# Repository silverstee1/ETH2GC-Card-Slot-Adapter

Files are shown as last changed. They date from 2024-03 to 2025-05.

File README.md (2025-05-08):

# ETH2GC-Card-Slot-Adapter
ETH2GC Card Slot PCB, Case Files

Card Slot Adapter on the front of the Gamecube for the ETH2GC BBA Emulation Project made by Extrems & WebHDX collab using the ENC28J60 Module.

https://github.com/Extrems

https://github.com/webhdx

~~BBA Emulation is not currently supported on the front slots but other network features such as FSP and Disc/IPL Dumping and more are accessible see swiss-gc github for more details.~~

As of swiss_1644 artifact build and Swiss Release Swiss v0.6r1664, BBA emulation has been added to Swiss Hypervisor and works on the front slots. See swiss build commit for more details.

Disc iso streaming is not supported on the ENC28J60

https://github.com/emukidid/swiss-gc

# Check out the newer, smaller, and more powerful card slot version based on the W5500 module below

https://github.com/silverstee1/WizNet-Card-Slot-Adapter - W5500 Version

# PCB Fab:
When ordering for example from JLCPCB, Select 1.6mm PCB thickness with ENIG surface finish for long life wear and tear, I choose HASL for cheap 1 off tests.

On the bottom of the PCB is 2x5 female 2.54mm pin connector soldered to the PCB to mate with the ENC28J60 Module once assembled.

**3D Printing:** I printed in PLA+ with the model standing up, the Ethernet Jack facing down on the build plate with Tree supports set to auto on my FDM Bambu X1C printer.
for the cover I had it facing flat side down on the build plate.

Case modified from WebHDX's Thingiverse gecko case https://www.thingiverse.com/thing:4866325

**Fastening:** I used M2x4 pan head self tapping phillips screws from a generic amazon kit for the 4 screw posts but a better alternative is M2x5 countersunk self tapping screws for a flat smooth finish.

1-min
2-min
3-min
4-min
5-min
6-min
7-min
8-min

**SLIM VERSION**

Slim Version requires a bit more DIY, desoldering c1 capacitor and relocating it to top connecting pin 1 of the chip to capacitor the otherside of the capacitor to ground plane scrapped off on the board, desoldering Crystal and resoldering it sideways, and soldering the bottom of the ENC28J60 pins to the top of the adapter PCB as flush as possible then snipping off the top of the pins on the ENC28J60 module, ~~currently awaiting test PCB for SLIM version to make it easier~~.

Case Already posted in Slim Cases, hopefully slim pcb can resolve the C1 cap relocation and only need the crystal to be desoldered and resoldered sideways.

TODO:
- ~~Waiting to test Slim version PCB.~~

Slim PCB works without the need for C1 relocation, the 25mhz crystal still needs to be soldered sideways with slim pcb.

20240415_181819-min
20240415_181835-min
20240415_181759-min
20240415_181723-min
20240415_181659-min
20240415_181625-min
20240415_181548-min
20240415_181509-min

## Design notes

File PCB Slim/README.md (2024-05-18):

Slim PCB gerbers, these don't need the C1 Cap relocation of the ENC28J60 but the 25mhz Crystal still needs to be mounted sideways for a flush top fit.

  slimpcb

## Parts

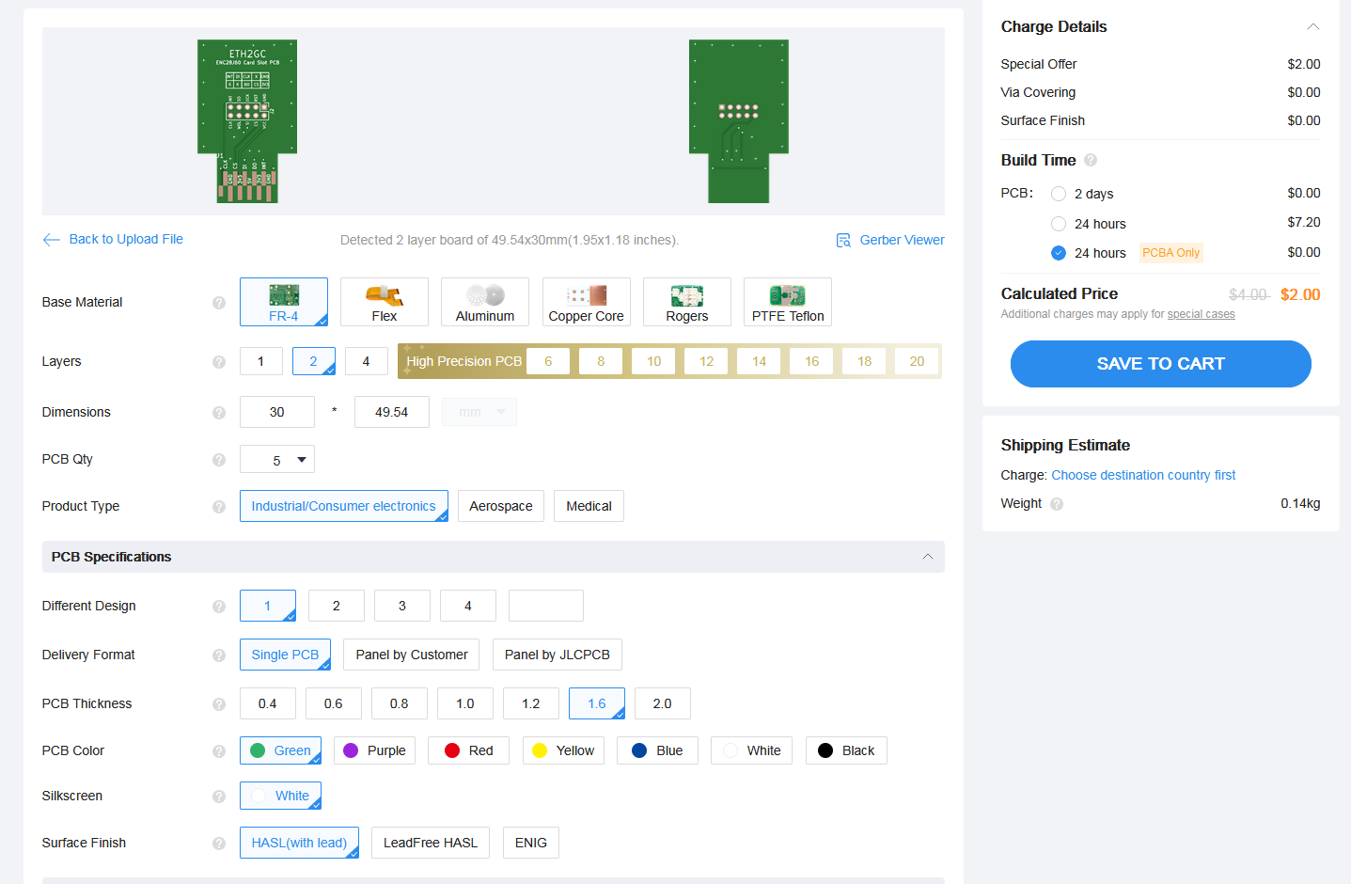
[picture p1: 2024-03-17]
PCB/JLCPCB Example Order.PNG

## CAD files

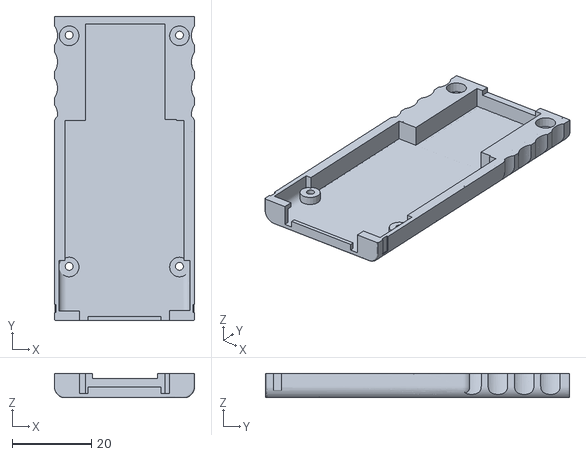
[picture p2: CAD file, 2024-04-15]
Case Slim/ETH2GC Slim CardSlot BottomV1.3.stl
35.5 x 76.9 x 6.10

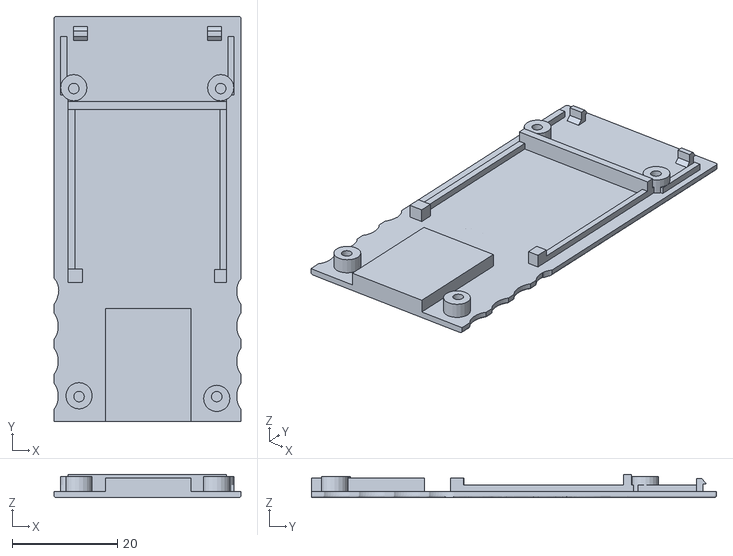
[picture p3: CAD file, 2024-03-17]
Case STLs/ETH2GC CardSlot Top1.stl
35.5 x 76.9 x 4.40

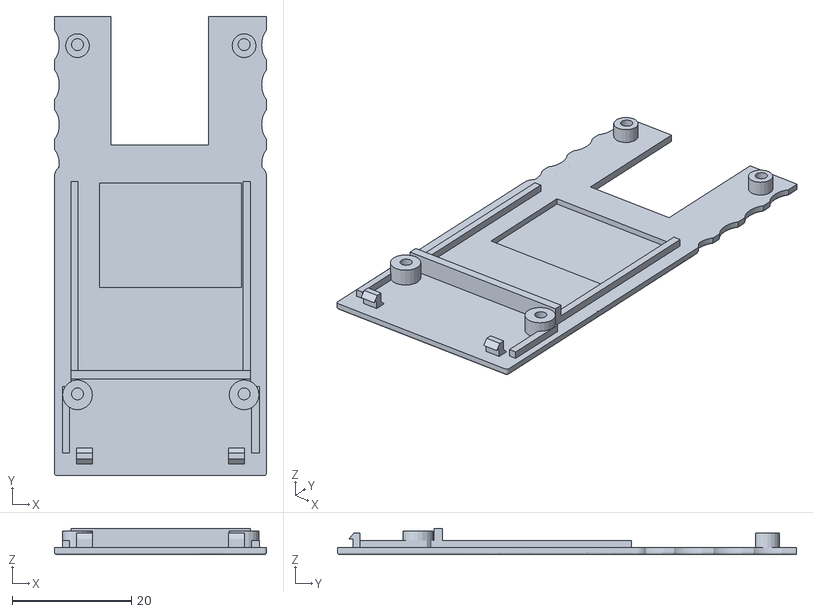
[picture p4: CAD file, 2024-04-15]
Case Slim/ETH2GC Slim CardSlot TopV1.2.stl
35.5 x 76.9 x 4.40

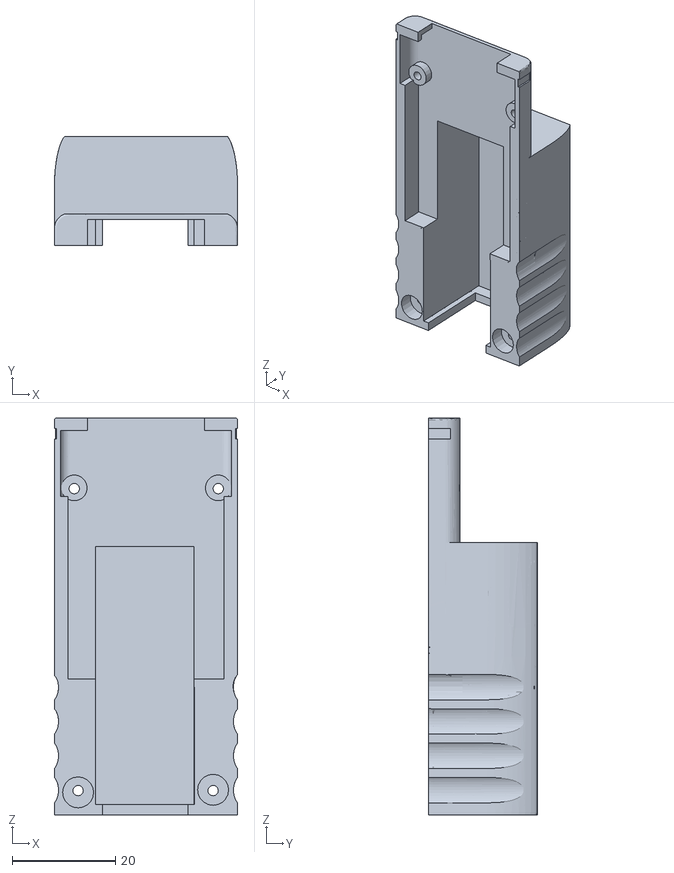
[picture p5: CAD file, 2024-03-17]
Case STLs/ETH2GC CardSlot Bottom1.2.stl
35.5 x 21.1 x 76.9

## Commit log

2024-03-17 added case stl's and pcb gerbers
    [ETH2GC Bottom1.2.stl, ETH2GC Top1.2.stl]
2024-03-17 Delete Case STLs/ETH2GC Top1.2.stl
    wrong orientation
    [ETH2GC Top1.2.stl]
2024-03-17 fixed orientation
    [ETH2GC CardSlot Bottom1.2.stl, ETH2GC CardSlot Top1.stl]
2024-03-17 Delete Case STLs/ETH2GC Bottom1.2.stl
    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
    [ETH2GC Bottom1.2.stl]
2024-04-15 Added Slim Version Case
    Slim Version Case for those who feel up to a challenge.
    [ETH2GC Slim CardSlot BottomV1.3.stl, ETH2GC Slim CardSlot TopV1.2.stl]
2024-05-08 added Slim PCB Gerbers
    modified pcb for slim version without the need to relocate the C1 cap to the top, although 25mhz crystal still needs to be mounted on the side.
